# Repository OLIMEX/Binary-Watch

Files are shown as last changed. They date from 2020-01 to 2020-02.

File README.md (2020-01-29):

# Binary-Watch

Binary Watch soldering kit with SMT components

Product page: https://www.olimex.com/Products/Soldering-Kits/Binary-Watch/open-source-hardware

## License
* Hardware is with CERN OHL v1.2 license
* Software is released under GPL3 License
* Documentation is released under CC BY-SA 3.0

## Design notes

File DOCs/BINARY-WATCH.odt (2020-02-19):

BINARY-WATCH assembly cheatsheet

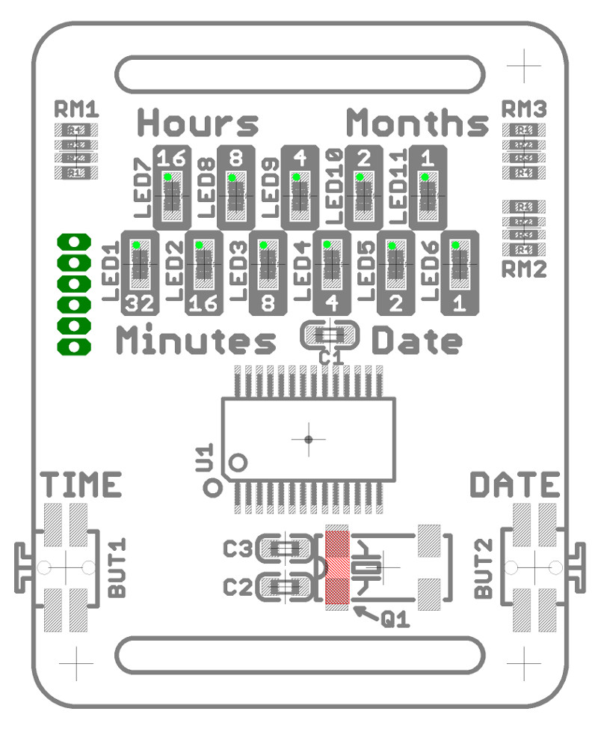
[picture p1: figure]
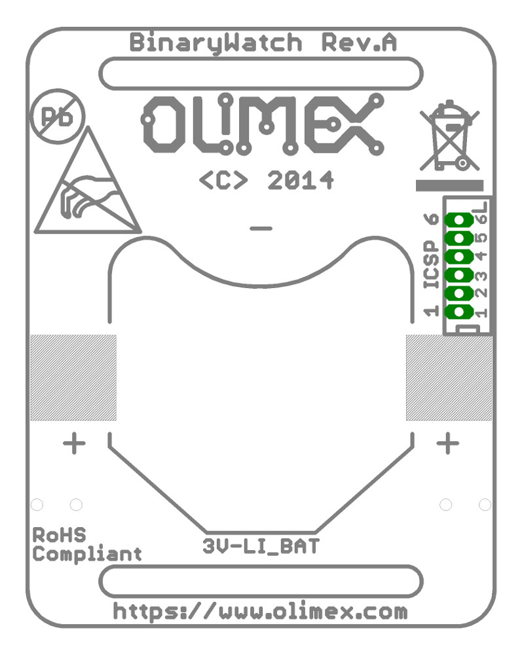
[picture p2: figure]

Binary-Watch design is made with small SMT components in mind.

There are several ways how to assemble the SMT components, the harder one requires no extra tools but experience with soldering iron, good eyesight. You hold the components with tweezers then solder the legs one by one.

Easier assembly process for SMT components requires some tools and preparation and follows these steps:

(1) Apply solder paste, (2) place the components, (3) reflow.

Refer to “Assembly_SMT.pdf” for more information about the process.

Capacitors:

Name | Size | Value
C1 | 0603 | 100nF, 50VDC, 10%
C2, C3 | 0603 | 10pF, 50VDC, 10%

Resistor matrices:

Name | Size | Value
RM1, RM2, RM3 | 4×0603 | 4.7K, 5%

LEDs:

LEDs must be placed with the green stripe/dot facing top of the pad. Make sure the lighting part is facing towards you.

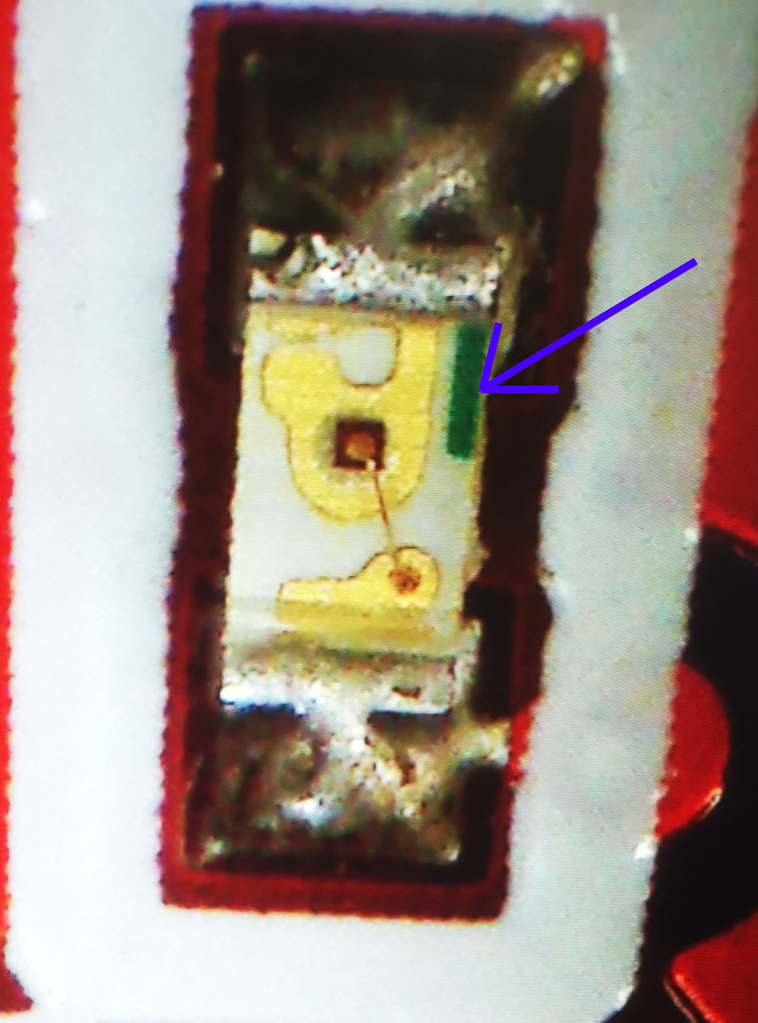
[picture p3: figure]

Name | Size | Value
LED1..LED6 | 0603 | GREEN 100mCd
LED7..LED11 | 0603 | RED 100 mCd

Buttons:

Name | Value
BUT1, BUT2 | WTCM-TR

MCU:

Warning first pin is marked with DOT!

Name | Size | Value
U1 | SSOP28 | PIC16F722A-I/SS

Quartz:

Name | Size | Value
Q1 | 1206 | CM7V-T1A 32.768kHz 12.5pF 20ppm

BAT holder:

Name | Value
3V-LI_BAT | BC2001

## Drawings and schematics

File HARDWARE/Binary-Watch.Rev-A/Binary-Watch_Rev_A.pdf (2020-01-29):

ICSP | Battery

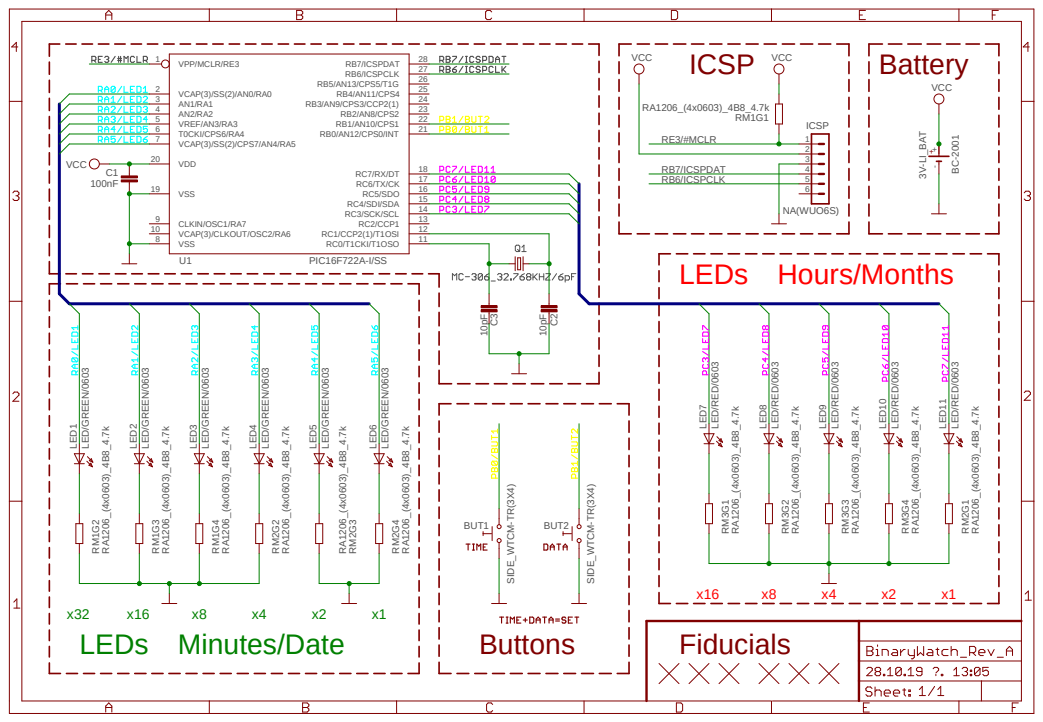
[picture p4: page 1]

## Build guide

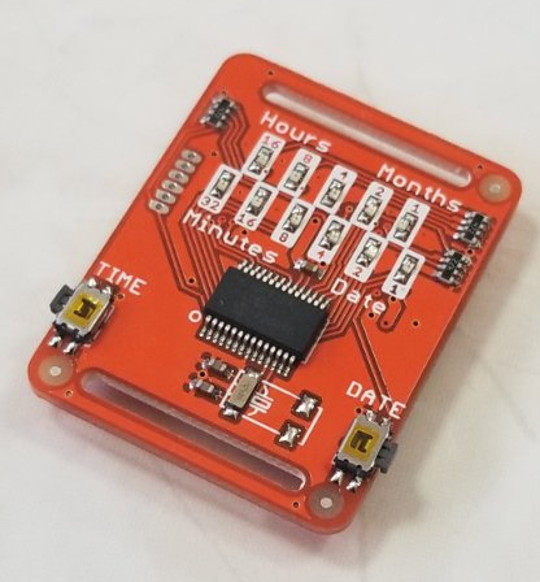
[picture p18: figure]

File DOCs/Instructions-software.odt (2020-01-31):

How to operate the Olimex Binary-Watch

After a successful assembly insert the CR2032 battery. Upon inserting the battery on a brand new board you would need to first set the time and date. Refer to "i. Setting the time and date".

i. Setting the time and date

1. In order to enter the mode for setting date and time press TIME and DATE buttons simultaneously. Doing so would light consequently each of the LEDs starting from bottom right to top left.

2. The way you set time and date is always in the same order – TIME: MINUTES -> TIME: HOURS -> DATE: MONTH -> DATE: DAY.

3. So would have to first enter the current time starting from the minutes and the lowest bit. How to do it?

There are only two states of each LED – 1 or 0 – LED lit or LED unlit. You can set the next state of the currently blinking LED by pressing down and holding the TIME button, the state of the LED seen while the button is pressed would remain after button is depressed (LED either lit or unlit). If you want the other state just release the TIME button and press it and hold it again – the two states change between presses. Once you have selected the state you want press DATE button to set it. Now you have to set the next bit and its LED would be now blinking by following the same procedure

There are 6 bits for minutes and day of month (2^5 = 32, 2^4 = 16, 2^3 = 8, 2^2 = 4, 2^1 = 2, 2^0 = 1) and 5 bits for hours and month (2^4 = 16, 2^3 = 8, 2^2 = 4, 2^1 = 2, 2^0 = 1).

For example: If you wish to set time 13 h and 55 minutes and date 2nd of February:

Start by setting the minutes to 55 as following:

1 | 2 | 4 | 8 | 16 | 32
1 | 2 | 4 | 0 | 16 | 32 | =55
1 | 1 | 1 | 0 | 1 | 1

Set the hour as following:

1 | 2 | 4 | 8 | 16
1 | 0 | 4 | 8 | 0 | =13
1 | 0 | 1 | 1 | 0

Now to the date, first set the month:

1 | 2 | 4 | 8 | 16
0 | 2 | 0 | 0 | 0 | =2
0 | 1 | 0 | 0 | 0

Finally set the day of the month:

1 | 2 | 4 | 8 | 16 | 32
0 | 2 | 0 | 0 | 0 | 0 | =2
0 | 0 | 0 | 0 | 0 | 0

Voila time and date are now set to 13h and 55 minutes of February the 2nd!

You might need to plan the time ahead until you get used to the settings, if you make a mistake just start all over by pressing TIME and DATE simultaneously.

ii. Checking the time and date (if previously set) - press either TIME or DATE button.

To check the current time, press and hold TIME button and calculate the time (sum all values at top row for hours; sum all values at bottom for minutes)

To check the month and the day of the month, press and hold DATE button and calculate the month and day of month (sum all values at top row for month; sum all values at bottom for day of month)

IMPORTANT! Do not press TIME and DATE buttons at the same time, this would reset the set time and date and force re-setting the time and date.

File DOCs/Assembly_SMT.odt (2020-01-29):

Assembly of SMT components without expensive tools

The SMT assembly contains three simple steps:

- Apply solder paste
- Place components
- Reflow soldering

Depending on your budget and scale of production you can have different setups but in this tutorial we will cover the very basic materials and instruments necessary.

Before we proceed let's learn a bit about the materials used:

SOLDER PASTE

Solder paste is made of small tin alloy particles mixed with tackle flux.

The ROHS industry standard used paste is SAC305 which has content of Sn 96.5% Ag 3% Cu 0.5%.

The function of the solder paste is to hold the component placed on the PCB, then when heated to solder the component pads to the PCB.

The tin alloy particles in the solder paste are with sizes typically from 20μm up to 45μm. Solder paste Class defines the size of the particles. Class 3 has particles from 25-45μm, Class 4 has particles from 20-38μm.

The number of solder particles in solder paste must be at least 4.5 times the smallest opening i.e. if you use Class 3 solder paste with 45 micron particles you will be able to print reliable only pads which are above 200 microns (0.2mm) size.

Class 4 is used when small pitch components has to be soldered like BGA 0.5 mm step or QFN 0.4 mm step. The smaller the particles – the better and the more expensive the paste. Class 4 is more expensive than Class 3.

Solder paste should be kept in refrigerator at 5-6C temperature when not used. Make sure it doesn't freeze, as the flux will change its properties. It should not be kept at higher temperatures than 22-24C for long time as the flux separation would happen i.e. the heavy metal contents will settle down and the flux will go up.

When solder paste is taken from the refrigerator it needs to be left at room temperature for at least 4-5 hours to heat up. Do not forcibly heat the paste.

Before applying the past you have to stir it very good to achieve the same viscosity.

Solder paste should not be left in contact with air for long, as it tends to absorb moisture and the flux evaporates. Usually the time solder paste can be left in open air is called solder paste “open time” and it's usually accumulated 24 hours.

Solder paste which has been used and exposed on open air can be reused again but it's a good idea to mix it with fresh paste 50%-50%.

STENCIL

Stencil is used to apply solder paste to the PCB easily.

When printing solder paste tack on stencil walls, so to may release good amount of paste there should be Area ratio >= 0.66

What is area ratio: this is the pad area divided by the stencil wall area.

If the pad size is L * W and the stencil is with thickness “t” the Area ratio is:

L * W / 2 * t * (L + W)

So for smaller pads thinner stencils should be used.

Standard stencil thickness is 0.1 mm, 0.12 mm, 0.15mm. What mostly is used is 0.12mm. If you have to deal with 0.5 mm step BGA and 0.3mm step QFNs you should use 0.1 mm stencil to achieve good Area ratio.

SQUEEGEE

Squeegee is a thin, flat, and smooth tool used to apply the solder paste evenly. It can be made of metal or rubber. Sometimes a plastic card or metal spatula can be used. When metal tip tool is used, the amount of solder paste is always same. When the squeegee is rubber the amount of solder paste may be changed by apply more or less pressure when printing.

REFLOW

The reflow process depends on solder paste used. If this is SAC305 type solder paste there are usually three phases:

Preheat: takes between 60 and 80 seconds and rise the temperature from 20C to 150C the temperature should not rise with more than 2C/sec. During this phase the flux in the solder paste is activated, some of flux volatile components evaporate and flux starts to eliminate the oxides in the PCB and component parts.

Soak: this lasts between 60 and 120 seconds. The temperature will change from 150 to 220C. During this phase all components on the PCB should have enough time to heat up so there is no thermal shock when PCB is entering next phase. The bigger components you have more time is necessary for the PCB to stay at this phase.

Reflow: During this phase the temperature should rise from 220C up to 240C for about 5-10 seconds then to decrease back to 220C. In this phase solder paste becomes liquid (SAC305 melting temperature is 217-220C), and should stay liquid at least for 30 seconds so the solder tin make good bond with the PCB copper and component pads.

Cooling: during this phase PCB cools from 220 to 20C it should not cool with more than 4C/seconds as deformations may occur.

Apply solder paste

To apply the solder paste to the PCB you need stencil printer or you can make simple DIY solution – fix your PCB to flat surface so it's not moving then fix the stencil above the PCB so the stencil openings are exactly at the PCB pads where paste is to be printed:

1. You need flat surface, we will use tile as it has good flat surface and will also protect the table later from heat when we do the reflow:

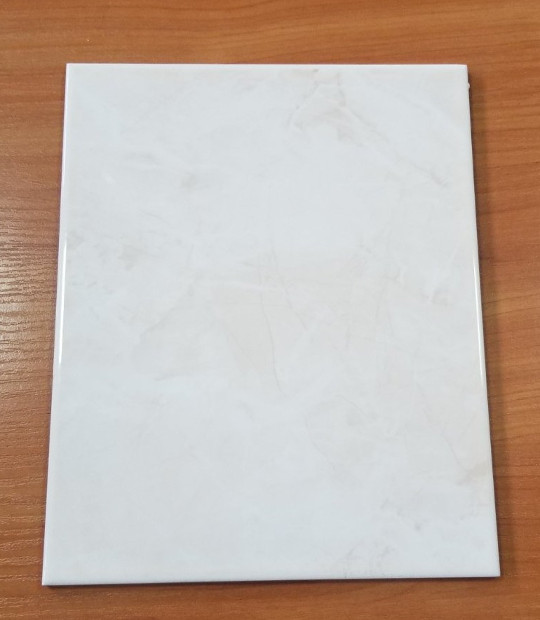
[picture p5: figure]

we place the board which will be assembled:

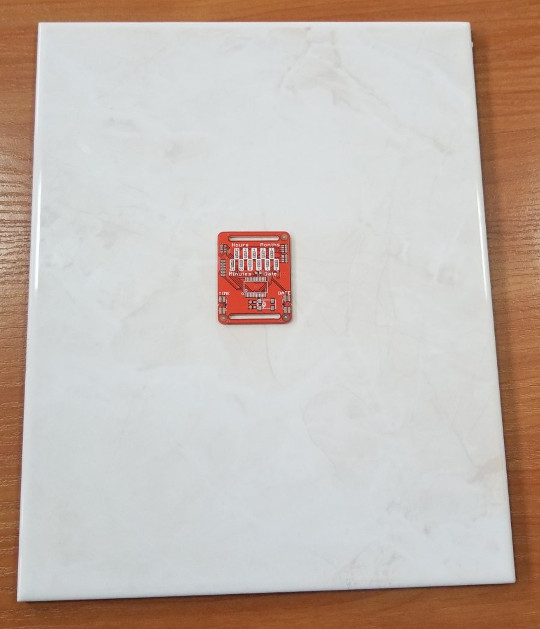
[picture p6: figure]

and fix it with some other boards with same height:

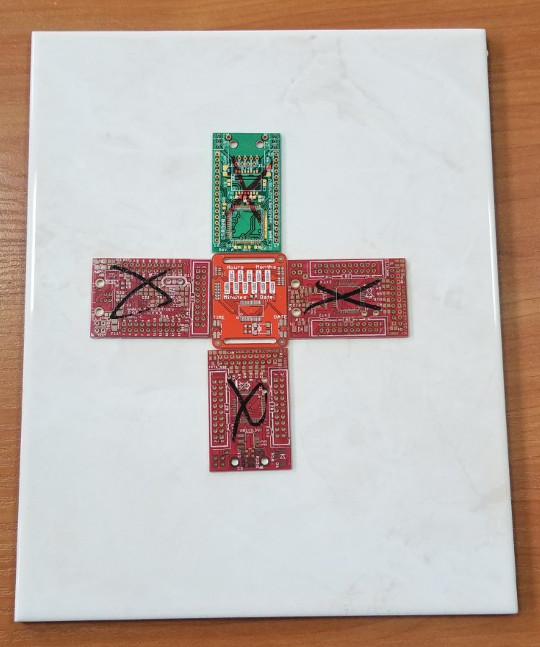
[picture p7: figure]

then tape them to stay firmly in place:

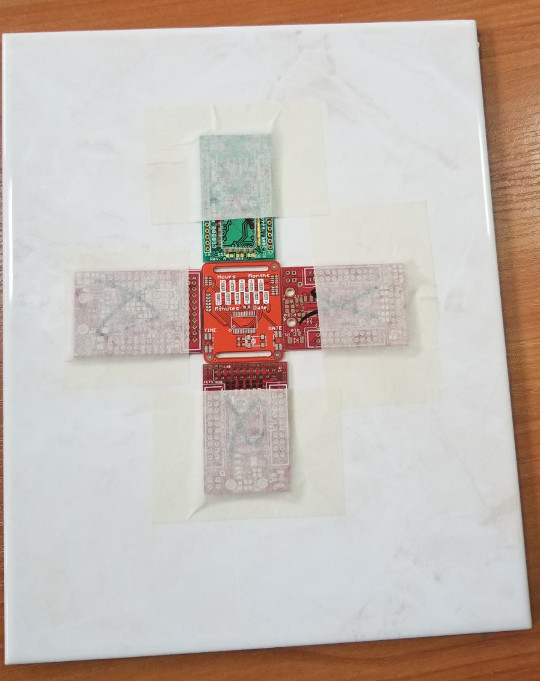
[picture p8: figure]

Now you can place all boards for soldermask printing in exactly the same position:

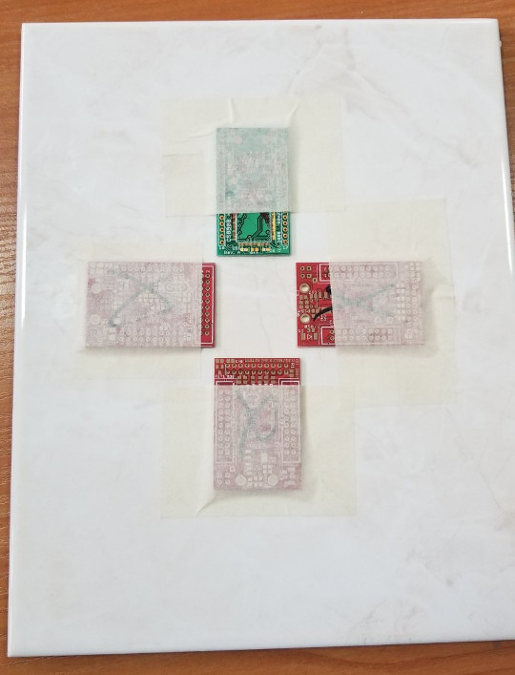
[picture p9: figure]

Now position the metal stencil so the pad openings match exactly the PCB pads and tape it so it doesn't move:

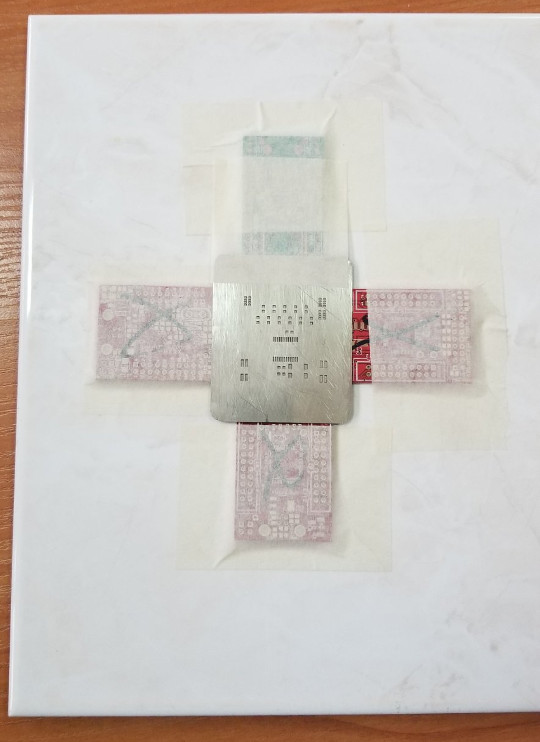
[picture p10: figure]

Open the solderpaste jar and mix it very well for several minutes so the flux mix well with the solder particles:

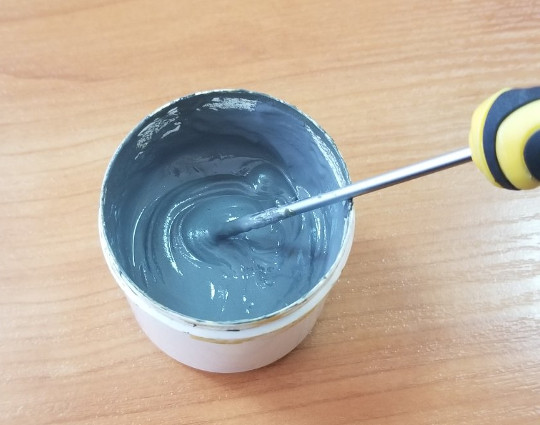
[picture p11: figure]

Put some paste on top of the PCB:

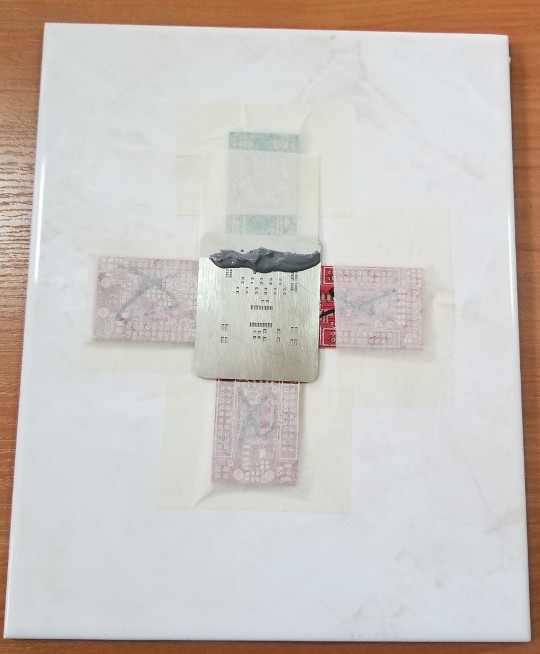
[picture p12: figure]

Then press the squeegee tool and move it from top to bottom of PCB without stop and carefully lift the stencil:

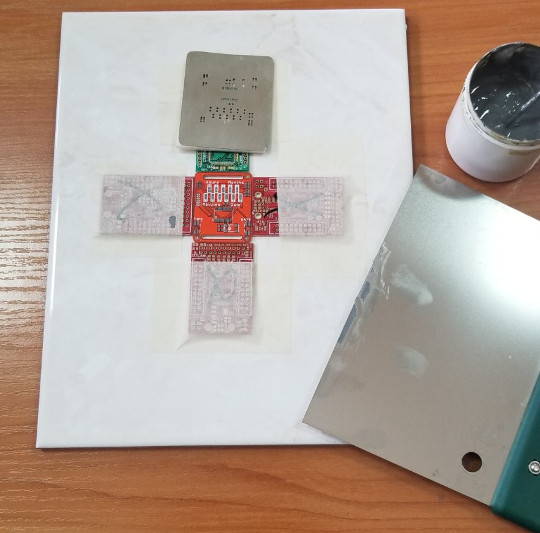
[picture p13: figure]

The solder paste should be printed on the pads and cover them with sharp edges without bridges between near pads:

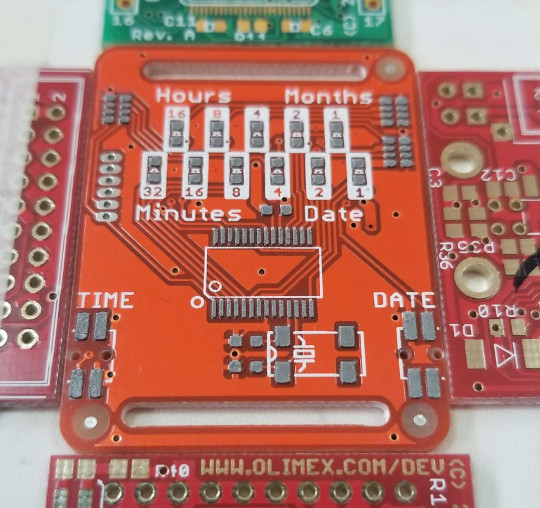
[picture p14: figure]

The PCB is ready for assembly:

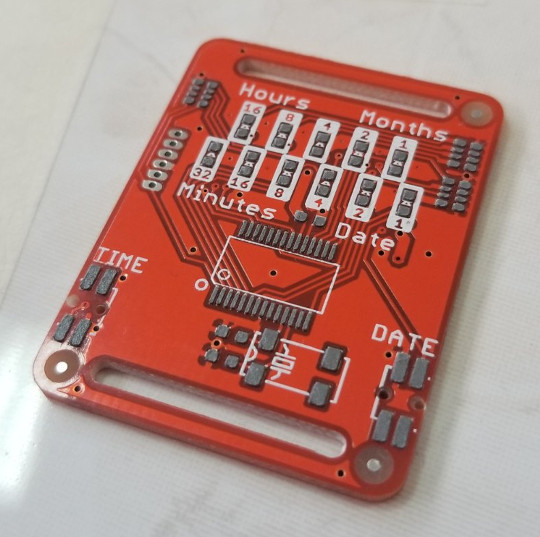
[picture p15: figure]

Place components

Components can be placed with tweezers or vacuum nozzle:

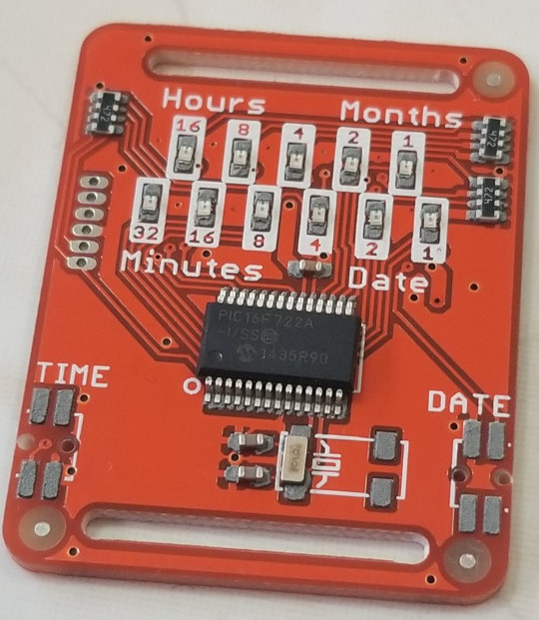
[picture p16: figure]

Do not worry if they are not perfectly aligned, during the reflow the melted alloy forces will align them:

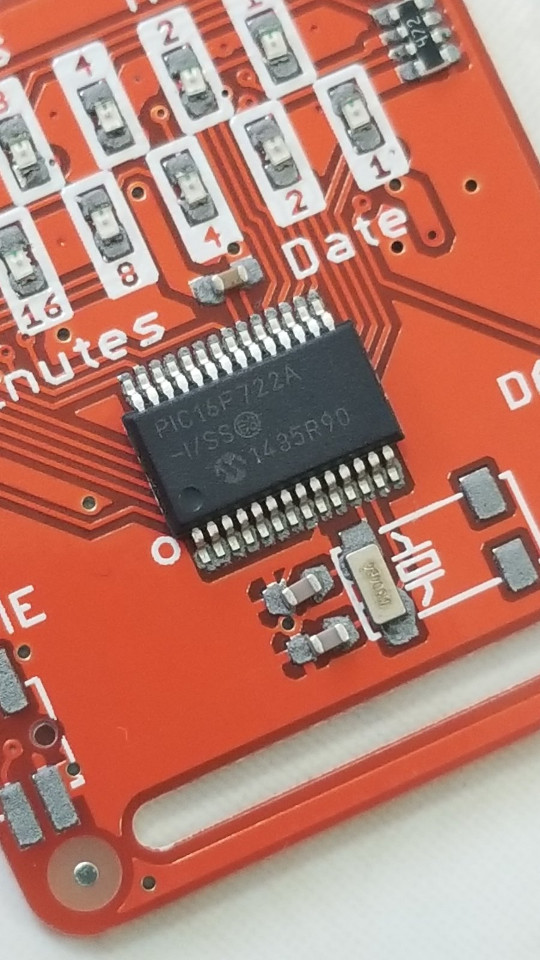
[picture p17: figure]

Reflow

The simplest way to reflow is by using hot air gun. Set the temperature to 350C and start heating the board with circulating movements above all PCB area so all PCB get equally heated. It will take 2-3 minutes before solder start to melt, be patient do not heat too fast as this may damage the PCB. When the solder paste start to melt do not stop but make sure it stay at least 20-30 seconds in liquid state to make reliable solder joint. Good solder joints are shiny and smooth:
